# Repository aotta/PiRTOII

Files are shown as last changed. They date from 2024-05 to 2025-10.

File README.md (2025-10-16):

# PiRTO II
Intellivision flash multicart based on Pico clone

PiRTO II  is the new version of my PiRTO multicart DIY yourself based on cheap "purple" Raspberry Pi Pico clone.

(use "alternate_boot" version if your PiRTO doesn't start without resetting it and/or the console).

added v. 1.01: bug fixed (added test if more than 64 files in a folder)

added v. 1.02: bug fixed (fix for Coleco Rom from previous version)

added v. 1.03: bug fixed (issue in Chess after move #21)

added v. 1.04: bug fixed Missile Domination (added support for both RAM8 and RAM16) and added initialization fix used by gtortone for his "Minty" for better compatibility

added v. 1.05beta Arduino IDE version, new environment left more ram space and let games until 180kb run. Fixed Time Pilot. WARNING!!! THIS NEW VERSION USE A NEW FILE SYSTEM AND YOU NEED TO FORMAT THE PICO FLASH AND RE-UPLOAD ALL BIN+CFG FILES!!!!!

**WARNING!** "purple" Pico has not the same pinout of original Raspberry "green" ones, you MUST use the clone or you may damage your hardware.

**NOTE** FAT FS used for flash file management is quite simple, you can't use FILENAME LONGER THAN 32 BYTES INCLUDED SUFFIX!!!!! 
PLEASE RENAME YOUR BIN FILES OR THE GAMES WON'T START AT ALL!!! 

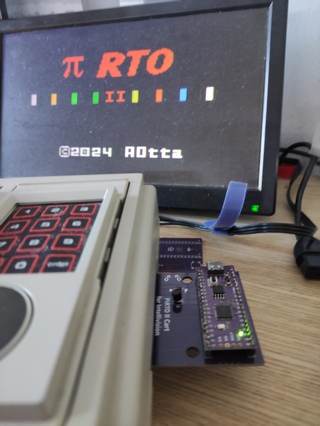
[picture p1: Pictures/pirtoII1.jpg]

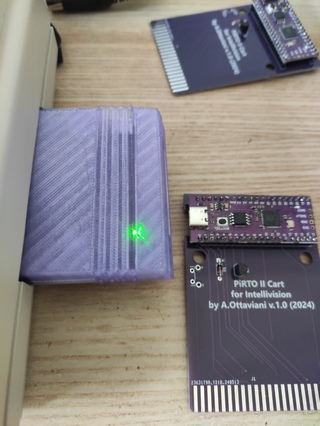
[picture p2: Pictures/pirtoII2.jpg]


Kicad project and gerbers files for the pcb are in the PCB folder, you need only a diode and a push buttons for resetting the cart if needed or want restart. 
Add you pico clone, and flash the firmware ".uf2" in the Pico by connecting it while pressing button on Pico and drop it in the opened windows on PC.
After flashed with firmware, and every time you have to change your ROMS repository, you can simply connect the Pico to PC and drag&drop "BIN" and "CFG“ files  into.

More info on AtariAge forum: https://forums.atariage.com/

Even if the diode should protect your console, **DO NOT CONNECT PICO WHILE INSERTED IN A POWERED ON CONSOLE!**
You can use any schottky diode, i usually put 1n4148

## Credits
Thank to Robin Robin Edwards and his A8PicoCart (https://github.com/robinhedwards/A8PicoCart), i found very smart his way to manage the Flash RAM and the USB updates, so i admit i took large parte of his code for it!.

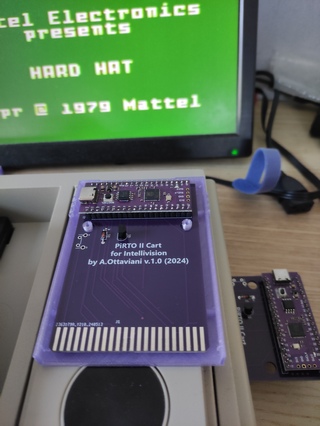
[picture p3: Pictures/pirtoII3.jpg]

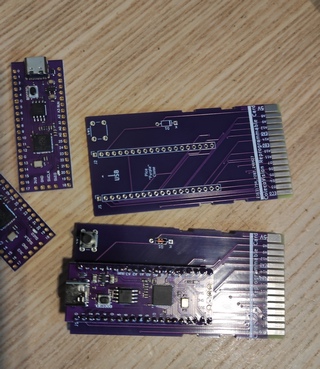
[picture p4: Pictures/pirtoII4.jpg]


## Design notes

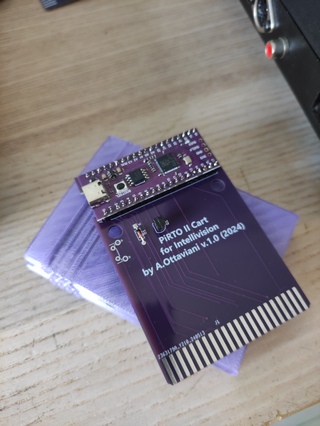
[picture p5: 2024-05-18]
Pictures/pirtoII6.jpg

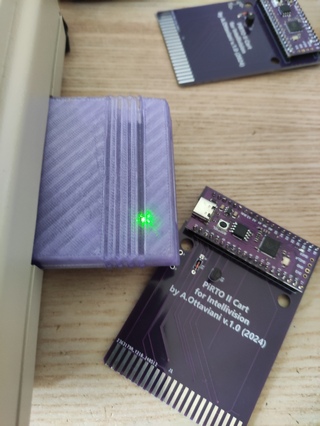
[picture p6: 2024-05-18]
Pictures/pirtoII7.jpg

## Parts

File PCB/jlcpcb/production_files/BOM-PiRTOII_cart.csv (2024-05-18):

Comment | Designator | Footprint | LCSC
Conn_01x20 | J2 | PinSocket_1x20_P2.54mm_Vertical
2x22 card edge connector | J1 | edge mounted 44 pin card edge connector (2x22 pin)
SW_Push | SW1 | SW_Tactile_SPST_Angled_PTS645Vx83-2LFS
Conn_01x20 | J3 | PinSocket_1x20_P2.54mm_Vertical
Diode | D1 | D_DO-35_SOD27_P7.62mm_Horizontal
BC547 | Q1 | TO-92_Inline

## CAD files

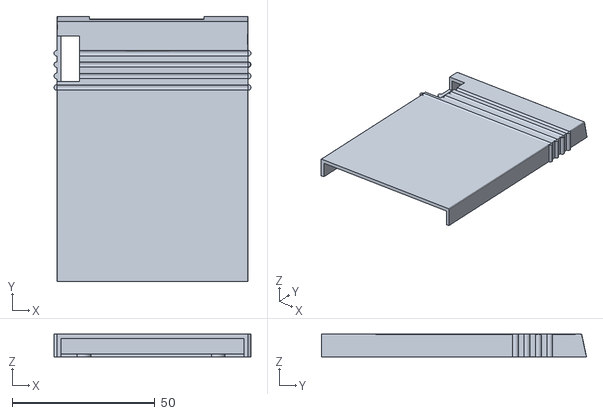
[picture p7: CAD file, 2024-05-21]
3DModel/PiRTOII/PiRTOII_Cart-Top (Meshed).stl
69.0 x 92.9 x 8.00

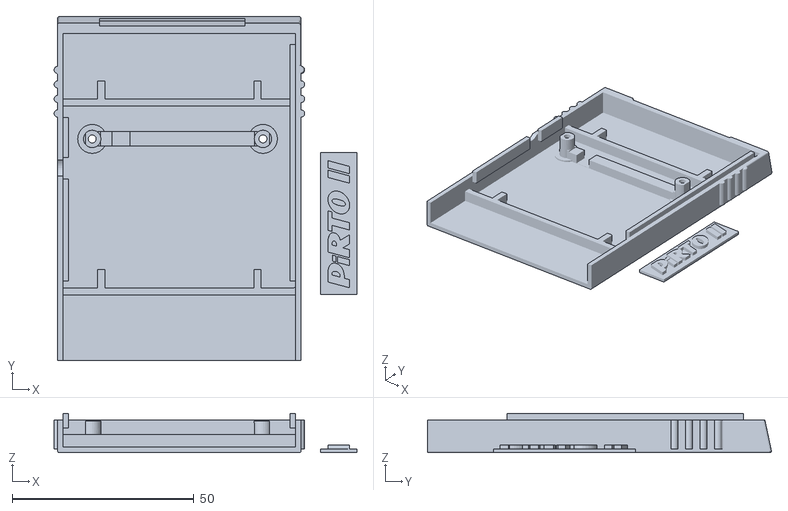
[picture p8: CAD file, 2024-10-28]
3DModel/Shell PirtoII Eskimo version/PiRTO_II-Cart-Bottom+Logo.stl
83.4 x 94.7 x 10.8

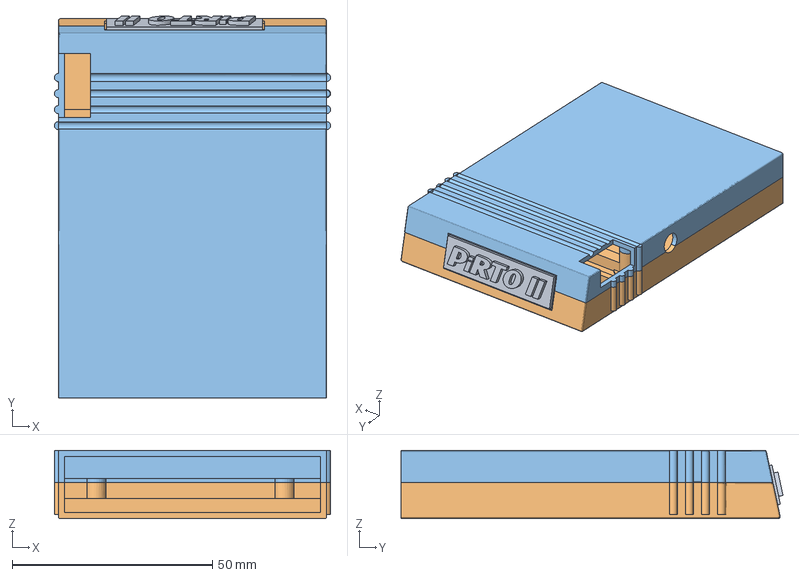
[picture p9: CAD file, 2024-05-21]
3DModel/PiRTOII/PiRTOII_Cart.FCStd
69.0 x 95.4 x 17.0 mm
Logo (Meshed)
Bot (Meshed)
Top (Meshed)

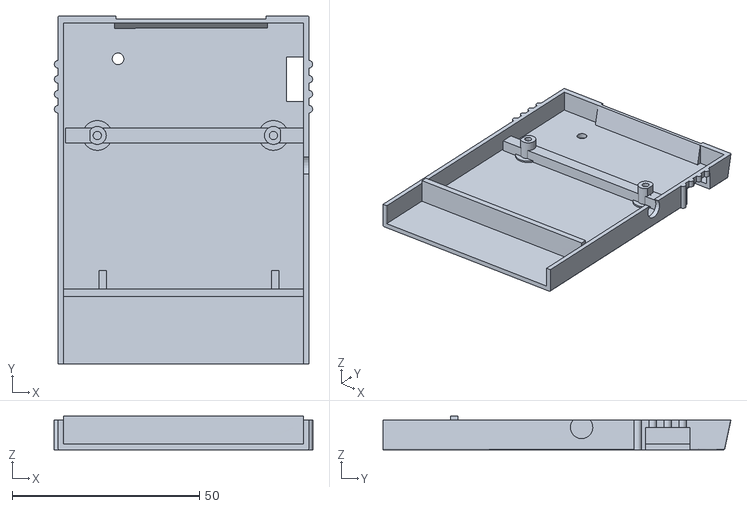
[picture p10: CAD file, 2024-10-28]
3DModel/Shell PirtoII Eskimo version/PiRTO_II-Cart-Top.stl
69.0 x 92.9 x 9.00

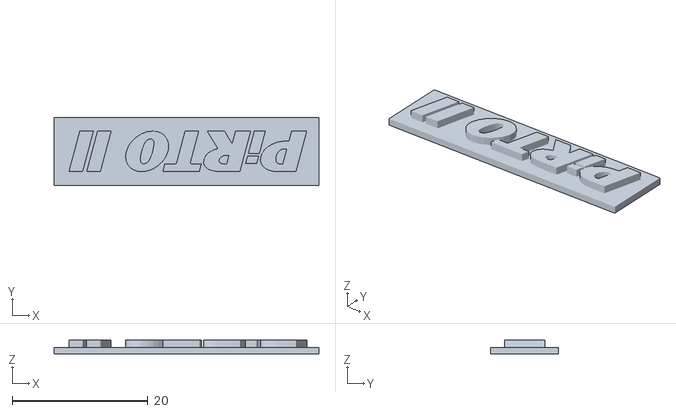
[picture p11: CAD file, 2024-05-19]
3DModel/PiRTOII/PiRTOII_Cart-Logo (Meshed).stl
39.0 x 10.0 x 2.10

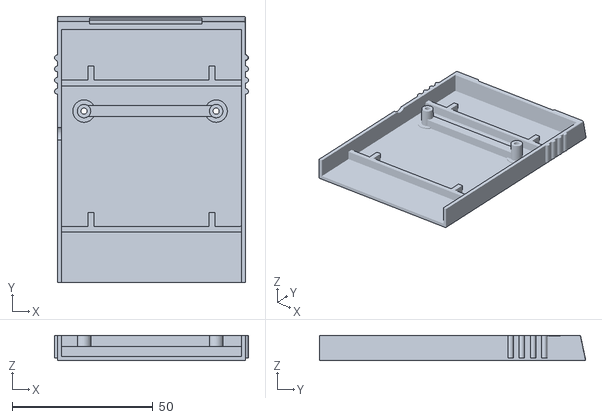
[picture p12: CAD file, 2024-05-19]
3DModel/PiRTOII/PiRTOII_Cart-Bot (Meshed).stl
69.0 x 94.7 x 9.00

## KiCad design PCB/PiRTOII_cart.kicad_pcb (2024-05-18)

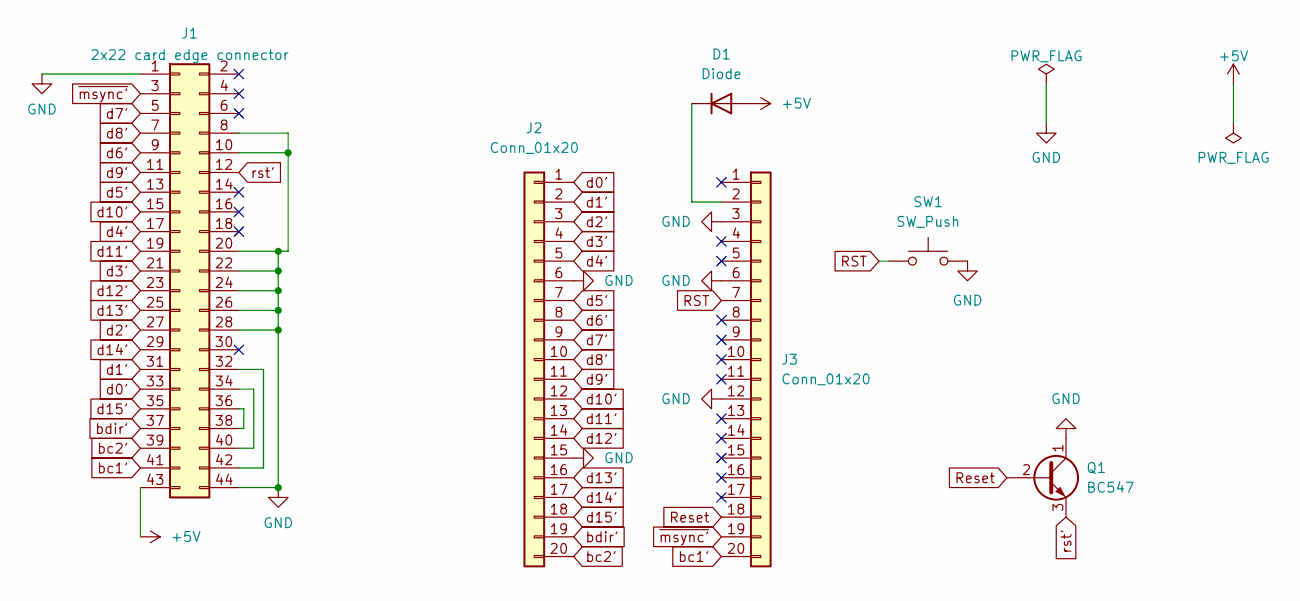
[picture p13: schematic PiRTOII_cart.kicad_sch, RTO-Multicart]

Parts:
D1: Diode; D_DO-35_SOD27_P7.62mm_Horizontal
J1: 2x22 card edge connector; edge mounted 44 pin card edge connector (2x22 pin)
J2, J3: Conn_01x20; PinSocket_1x20_P2.54mm_Vertical
Q1: BC547; TO-92_Inline
SW1: SW_Push; SW_Tactile_SPST_Angled_PTS645Vx83-2LFS

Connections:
+5V: D1.2 (A), J1.43
GND: J1.1, J1.8, J1.10, J1.20, J1.22, J1.24, J1.26, J1.28, J1.44, J2.6, J2.15, J3.3, J3.6, J3.12, Q1.1 (C), SW1.2
unnamed: D1.1 (K), J3.2
unnamed: J1.32, J1.42
unnamed: J1.34, J1.40
unnamed: J1.36, J1.38
RST: J3.7, SW1.1
Reset: J3.18, Q1.2 (B)
bc1': J1.41, J3.20
bc2': J1.39, J2.20
bdir': J1.37, J2.19
d0': J1.33, J2.1
d1': J1.31, J2.2
d2': J1.27, J2.3
d3': J1.21, J2.4
d4': J1.17, J2.5
d5': J1.13, J2.7
d6': J1.9, J2.8
d7': J1.5, J2.9
d8': J1.7, J2.10
d9': J1.11, J2.11
d10': J1.15, J2.12
d11': J1.19, J2.13
d12': J1.23, J2.14
d13': J1.25, J2.16
d14': J1.29, J2.17
d15': J1.35, J2.18
rst': J1.12, Q1.3 (E)
~msync': J1.3, J3.19

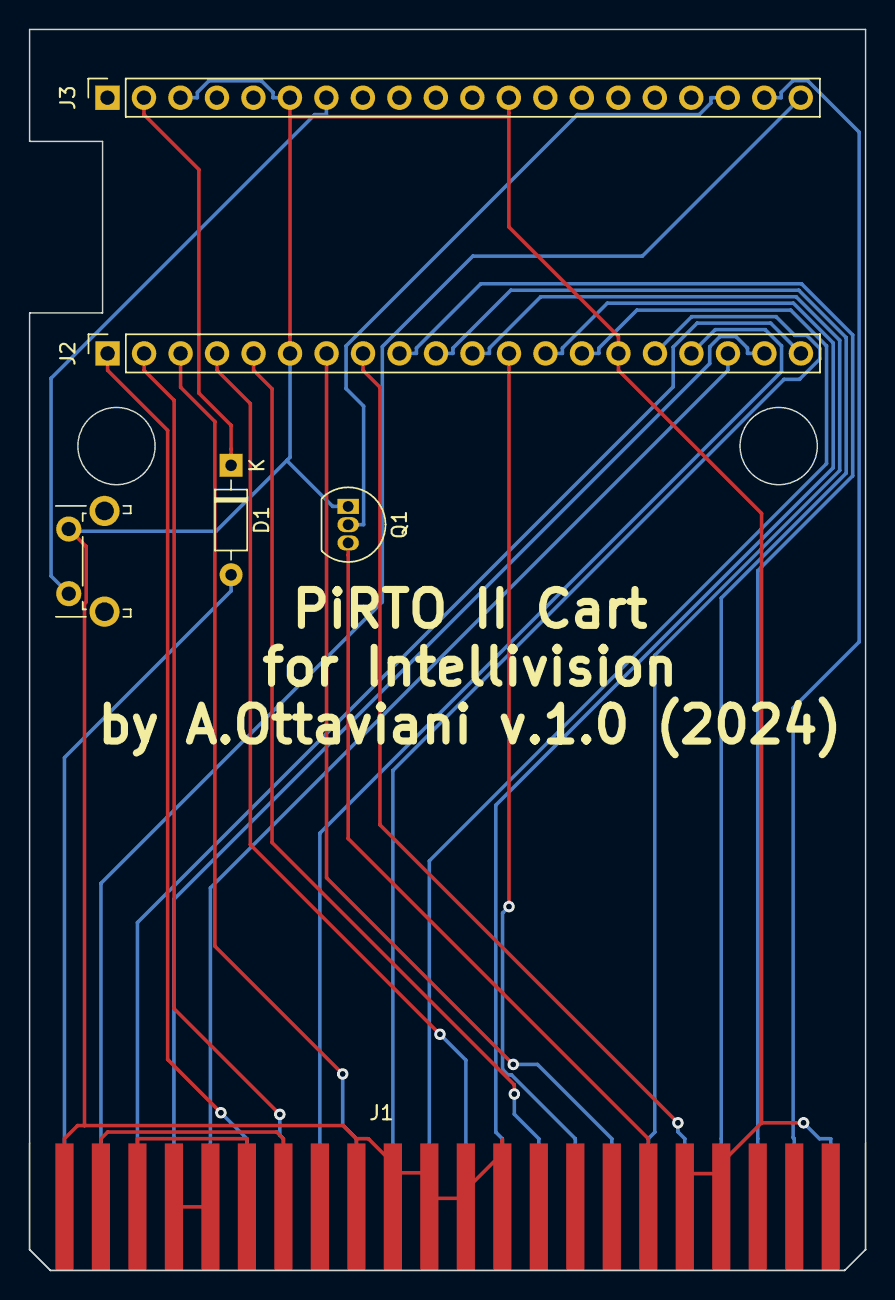
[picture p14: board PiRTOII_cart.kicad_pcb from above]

Board: 2 copper layers, 58.2 x 86.4 mm, 6 parts (0 on the bottom side), 29 nets.

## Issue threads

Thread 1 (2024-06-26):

Recommended edge connector option?

hadess, 2024-06-26:
I guess this question stands for most of your "flashcarts": which PCB thickness and edge connector finish do you recommend using? The defaults for my supplier are 1.6mm thick PCBs, and ENIG edge connector finish. Are those OK? What bevelling would you recommend?

aotta, 2024-06-26:
I used defaults also, in my case 1.6mm thick but Hasl with lead finish.
Enig should works fine too, but it's usually more expensive.
Gold fingers also may be a good options, but i wanted to keep all my
flashcart cheaper as possible.

Il giorno mer 26 giu 2024 alle ore 08:59 hadess ***@***.***>
ha scritto:

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

hadess, 2024-06-26:
The ENIG finish was relatively cheap (compared to shipping or VAT) and I went with 30 degrees bevelled edge as recommended here: https://www.retrorgb.com/determining-the-build-quality-of-a-game-cartridge.html

Thanks!

Closed 2025-03-10.

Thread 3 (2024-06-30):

A couple of design questions

SukkoPera, 2024-06-30:
I'm working on a modified version of this cart that used the original Pico board (just because I have plenty of those) and I have a few questions on the design. Please note that I don't know anything about the Intellivision. I have bought one some time ago but I have no carts, hence my interest in this project :). So please excuse me if my questions are naive, it's really the first time I look at this stuff:

* I see that pins 8 and 10 are permanently grounded. I can understand it for pin 8, which, according to [the pinout](https://wiki.intellivision.us/index.php/Cartridge_Port) is the EXT_VIDEO input (I guess it's for reducing noise), but not for pin 10: it looks like it is the MCLK _output_, and forcing it to ground doesn't sound good to me. I think it should just be left unconnected. Maybe you wanted to ground pins 6 (EXT_AUDIO) and 8 but you miscounted? Just a thought :).
* Same for pin 20, ROM_DISABLE: why is it grounded?
* The reset circuit does not look correct to me. The BC547 is an NPN transistor and seeing its collector connected to GND is very odd. Besides, I think some resistors should be added in series with the base and collector. Can you please explain the rationale behind it?

Thanks a lot! :)

SukkoPera, 2024-06-30:
This would be my proposal for the reset circuit:
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

(_reset_inty_out_ is the signal coming from the Pico, I've just renamed it)

SukkoPera, 2024-12-22:
I have finally tested my above proposal for the reset circuit and I can now say that it works perfectly! ;)

aotta, 2024-12-22:
Thank @SukkoPera for the alternative design, so close the issue

Closed 2024-12-22.

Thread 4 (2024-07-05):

Black screen on power up

repetto74, 2024-07-05:
Hi,

I have built this project. All soldering is good and checked. I used a diode 1N4148 and a BC547 transistor. No pushbutton installed for the reset.
Pico programmed from USB and bin files copied in the "PICOII" drive showing up on the desktop after firmware programming.

I get a black screen with a background video noise when I power up the Intellivision. This is the normal behaviour when no cart is inserted in the console.
Pico led is not lighting up. Looks like the Pico does not get power. Any idea what this could be?

aotta, 2024-07-05:
one user experimented similar issue due to not recognizing MSYNC signal at
boot, you could try the alternate firmware i just uploaded if it help

Il giorno ven 5 lug 2024 alle ore 19:27 repetto74 ***@***.***>
ha scritto:

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

repetto74, 2024-07-05:
Ok thanks I will give a try with the alternate firmware thanks :-)

repetto74, 2024-07-05:
I reprogrammed the pico with the alternate firmware (noticed that games binaries copied in the Pico are not cancelled but I assume this is normal).
Unfortunately same behaviour. Black screen with video noise in the background.

repetto74, 2024-07-05:
The pico is the purple clone as stated by the Ali merchant. Still a doubt maybe on the pinout of this one but I think it is the good one.
This is the one I picked for this project: https://www.aliexpress.com/item/1005007052696317.html?spm=a2g0o.order_list.order_list_main.5.3cc318022FPEpg

aotta, 2024-07-05:
So, sorry but that Pico clone has a different pinout than the usual
"purple" clone and it doesn't work with PiRTO.
As you could see, for example it has GND at pin no. 3 while the right one
has GND at pin no. 6, as better showed in the repository from which i was
inspired: https://github.com/robinhedwards/A8PicoCart

Il giorno ven 5 lug 2024 alle ore 20:13 repetto74 ***@***.***>
ha scritto:

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

repetto74, 2024-07-05:
Ok thanks now it is clear :-) ! I need to source the good Pico clone.

repetto74, 2024-07-05:
I finally found the good purple pico and ordered. This should fix the issue :-).

https://www.aliexpress.com/item/1005004277013272.html?spm=a2g0o.order_list.order_list_main.5.73e41802q3bytF

emilen72, 2024-07-06:
Hi, I have the same behavior and I built the cart with the same latest purple clone you ordered. The cart works but I need every time:
1) insert the cart
2) turn on the console
3) reset the console
4) reset the cart (install button or short with tweezers)

then the start menu and game are listed.
Remember to add the 0.cfg file in the root otherwise the games won’t start.

hope this help

aotta, 2024-07-06:
The user at atariage solved with the alternative FW in published yesterday, please @emilen72 check it you too

aotta, 2024-07-06:
A Pico clone with different pinout will never work without changes in PCB, and also trying it could damage your Pico and/or the console!

mamejay, 2024-07-07:
> The user at atariage solved with the alternative FW in published yesterday, please @emilen72 check it you too

PERFECT!! This works well.

emilen72, 2024-07-08:
> The user at atariage solved with the alternative FW in published yesterday, please @emilen72 check it you too

Ok, it work… only noted that on every game, after that the game start well, the led blink 1 time endless… its ok too?

bataais, 2025-01-31:
Unfortunately USCF Chess 'hangs' at white move 21 on the PiRTOii. Clocks are counting, but no move is made.
I have the right .bin and .cfg files.

Try it with C vs C, Color (Left Controller ENT, ENT, 8).

Seems a RAM problem..

Closed 2025-03-10.

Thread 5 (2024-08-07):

Incoherent code in "void __not_in_flash_func(core1_main())", in "inty_cart.c" module.

dombru54, 2024-08-07:
Hello,
There is an unconditional "break" in this "for", "break" should be in "if".
if (hacks>0) {
          for (int i=0; i<maxHacks;i++) {
            if (parallelBus==HACK[i]) {
              dataOut=HACK_CODE[i];
              deviceAddress = true;
            }
            break;
          }
        }

aotta, 2024-08-07:
Hi, you're right, break position fixed in source

dombru54, 2024-08-07:
Your welcome !
Congratulations, aotta, for your shared project.
I am putting it into service

Closed 2024-08-07.

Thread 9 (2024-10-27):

Question about rPico pinouts

8lall0, 2024-10-27:
I would like to ask what are the differences between the original rPico and the purple clone :)

Thanks!

crystalct, 2024-11-06:
Could you tell us where to read the characteristics of this clone which make it safe for the use of 5V in the GPIOs.....

SukkoPera, 2024-12-22:
It is never clearly stated, but I think that the board was designed for the purple clone because it can be bought with much larger flash size than the official board (16 MB vs 2 MB), thus more ROMs can be put on it.

The clone has no special characteristics that make it 5V-tolerant, it's just the RP2040 that [is *unofficially* 5V-tolerant](https://hackaday.com/2022/09/25/pi-pico-w-does-pcmcia-gets-this-ibm-pc110-online/#comment-6516402).

Anyway, you might be happy to know that I have designed [a variant of this board](https://github.com/SukkoPera/PiRTOII) that uses the official Pico and (re)introduces proper level shifting. Feel free to check it out! ;)

aotta, 2024-12-22:
I confirm the only real reasons why i used the purple clone is the 15mb flash free instead of the 780~kb of the green one.
Thank to @SukkoPera for his variant, now anyone could choose his favourite flavours.

Closed 2024-12-22.

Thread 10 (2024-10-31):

Games not loading, but Booting OK to the menu screen.

roninfourseven, 2024-10-31:
I have built a PiRTOII using PCBWay to manufacture the PCBs from the gerbers on here.

The Pi is a purple Pi from Ali Express and I bought two, one is installed in one of your PiColecos and works fine BTW.

The PiRTOII boots fine to the menu screen and I can navigate to ROMs (These have a BIN extension and the filenames are less than 32 characters), however whin I select a file it sits with the green light pulsing and the Intellivision is frozen.

The Intellivision works fine with normal carts.

I have tried both firmware versions but get the same and I have reflowed all the soldering.

One thing, my Intellivision is a UK model and I don't know if the ROMs are region sensitive.

Any help would be useful, thanks

Jon

roninfourseven, 2024-10-31:
I didn't, can you elaborate a little more please

MMarcoux66, 2024-10-31:
Look at this thread...  https://forums.atariage.com/topic/366700-pirto-ii-multicart-just-published/page/2/

roninfourseven, 2024-10-31:
Thank you

roninfourseven, 2024-10-31:
OK so 0.cfg has been added and it boots, but ends up at a black screen with the Purple Pi flashing it's light every other second.

roninfourseven, 2024-10-31:
Good news, I downloaded the cfg files from atariage and it seems to be working :)

aotta, 2024-10-31:
Happy you solved, closing.

Closed 2024-10-31.

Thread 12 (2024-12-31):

Diode value?

deelowe, 2024-12-31:
Perhaps I missing it, but I can't seem to find specifications for the diode used in the design. Can the part details be provided?

aotta, 2024-12-31:
Any diode should works, i usually use 1n4148

Closed 2024-12-31.

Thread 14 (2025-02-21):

Richiesta informazioni su progetto PIRTOII

Fing972, 2025-02-21:
Salve,
innanzi tutto complimenti per il progetto, avevo già iniziato a seguire la versione 1 ma, ora che mi sono deciso a volerla realizzare, vorrei direttamente  puntare alla versione 2 ma avrei necessità di alcuni chiarimenti, se possibile, dato che non sono particolarmente esperto.
Per prima cosa ho studiato il PCB e ho visto che è realizzato con un pico purple che dovrebbe supportare i 5v.
Ho letto che ufficialmente il pico lavora a 3.3v, io ho acquistato in passato dei pico e sono la versione yd-rp2040 a 16mb che probabilmente hanno un pinout da confrontare bene con il purple e forse dovrei inserire dei level shifter 3.3-5v per essere sicuro.
Il sorgente della prima versione del PIRTO era basato sull'arduino IDE (.ino) mentre la seconda versione ho dovuto capire come funziona l'SDK per raspberry, poco male, un po di esperienza in più e dopo un po sono riuscito a compilare il tutto.
Qui arrivano i dubbi.
Le rom nella prima versione venivano messe nella sdcard mentre non ho capito bene nella seconda come vengono gestite e come viene utilizzato il pacchetto intybasic con dentro i sorgenti basic per i title.
Grazie in anticipo per i chiarimenti.
Saluti.
Alessandro

aotta, 2025-02-22:
Una volta caricato il firmware, se connetti la pirto al pc via usb (non inserita nella console) si apre una finestra con la cartella flash e puoi copiare i file bin+cfg con un semplice drag & drop.
Il codice intybasic è per il menu ma non ti serve modificarlo

Fing972, 2025-03-05:
Salve,
ho realizzato un prototipo utilizzando però un pico yd-rp2040 con 16mb.
ho adattato la piedinatura e modificate le impostazioni per il tipo di memoria.
La compilazione è andata a buon fine, ho scritto il firmware e sull'intellivision appare la schermata principale.
Il problema che ho è che una volta effettuato il flash del firmware il pico non mi viene visto, una volta collegato al PC, come memoria di massa e quindi non riesco a copiare le rom. Se vado in bootsel e copio qualcosa, naturalmente poi i dati vengono persi.
Il pc ad un certo punto mi da un errore tipo usb non riconosciuto.
Se invece metto il firmware del micropyton, dopo il flash me lo riconosce come memoria di massa di circa 15mb.
Cosa potrebbe essere andato storto, ho provato tutte le versioni di firmware.
Forse qualche impostazione del flash_fs ?
Grazie.

aotta, 2025-03-05:
Il sistema "doppio" è gestito con le librerie TinyUSB, devi installarle e selezionarla come USBStrack nel compilatore Arduino IDE

Closed 2025-02-22.

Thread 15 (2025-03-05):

Problemi con il pico dopo il flash del firmware

Fing972, 2025-03-05:
Salve,
ho realizzato un prototipo utilizzando però un pico yd-rp2040 con 16mb.
Ho adattato la piedinatura e modificate le impostazioni per il tipo di memoria.
La compilazione è andata a buon fine, ho scritto il firmware e sull'intellivision appare la schermata principale.
Il problema che ho è che una volta effettuato il flash del firmware il pico non mi viene visto, una volta collegato al PC, come memoria di massa e quindi non riesco a copiare le rom.
Se vado in bootsel e copio qualcosa, naturalmente poi i dati vengono persi.
Il PC ad un certo punto mi da un errore tipo usb non riconosciuto.
Se invece metto il firmware del CircuitPython, dopo il flash me lo riconosce come memoria di massa di circa 15mb (è solo un esempio, cosi ho capito che in qualche modo il mio pico funziona come memoria di massa).
Cosa potrebbe essere andato storto, ho provato tutte le versioni di firmware.
Forse qualche impostazione del flash_fs che varie in base al tipo di flash memory ?
Grazie.

Closed 2025-03-10.

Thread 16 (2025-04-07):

What kind of diode ? (not an issue)

Giandj, 2025-04-07:
Hi Andrea,
what kind of diode do you use in your PIRTO II ?

I see the bom files, and readme.md, but no information about diode...

Instead Transistor is a  "BC547A NPN 45V 0.1A TO-92" ? (schematics is not so clear/absent ?)

Can you help me ?
Thank you

aotta, 2025-04-08:
already answered in a closed issue, and updated the readme for any convenience.
Anyway, any schottky diode should works, i usually put 1n4148 since i've tons

Closed 2025-04-08.

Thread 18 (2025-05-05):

error in latest firmware PIRTOII_cart_1.03.uf2

Giandj, 2025-05-05:
Hi,
After installing new firmware **PIRTOII_cart_1.03.uf2**, KChess game loads, but
after pressing joypad-wheel to enter in game it exit immediatly (due to an error, I Think)
whit a black screen on TV from game, hanging Pirto II... Until Reset Button wil be pressed...to reboot PiRTO II

So I think this new firmware has an issue with KChess game, other games works perfectly like in previously version  **PIRTOII_cart_1.01.uf2**

If I try to reflash old firmware PIRTOII_cart_1.01.uf2, the KChess game works very well (instead).

**I prefer to remain on PIRTOII_cart_1.01.uf2, most stable...**

Thank you

aotta, 2025-05-05:
With v.1.01, Chess hangs after 21 moves. V.1.03 fixed it. Did you try the ” alternate_boot” version?

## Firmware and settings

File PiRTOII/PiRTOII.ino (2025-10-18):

/*
//                       PiRTO II Flash MultiCART by Andrea Ottaviani 2024
//
//  Intellivision flash multicart based on Raspberry Pico board -
//
//  More info on https://github.com/aotta/ 
//
//   parts of code are directly from the A8PicoCart project by Robin Edwards 2023
//  
//   Needs to be a release NOT debug build for the cartridge emulation to work
// 
//   Edit myboard.h depending on the type of flash memory on the pico clone//
//
//   v. 1.03 2025-09-04 : Added check maxfile 
//   v. 1.05 porting to Arduino IDE - support rom until 180kb (Time Pilot)
//
*/

//#define intydebug // for debug print on intyscreen

/*
#include <stdio.h>
#include <stdlib.h>

#include "tusb.h"
*/
//#include "ff.h"

#include "hardware/gpio.h"
#include "pico/platform.h"
#include "pico/stdlib.h"
#include "hardware/vreg.h"
#include "pico/multicore.h"
#include "hardware/flash.h"
#include "hardware/sync.h"
#include "string.h"
#include "rom.h"
#include "dir_entry.hpp"
// include for Flash files
#include "SPI.h"
#include "SdFat_Adafruit_Fork.h"
#include "Adafruit_SPIFlash.h"
#include "Adafruit_TinyUSB.h"
Adafruit_FlashTransport_RP2040 flashTransport;
Adafruit_SPIFlash flash(&flashTransport);

// file system object from SdFat
FatVolume fatfs;
FatFile root;
FatFile file;

// USB Mass Storage object
Adafruit_USBD_MSC usb_msc;
// Check if flash is formatted
bool fs_formatted;
// Set to true when PC write to flash
bool fs_changed=false;


// Pico pin usage definitions

#define B0_PIN    0
#define B1_PIN    1
#define B2_PIN    2
#define B3_PIN    3
#define B4_PIN    4
#define B5_PIN    5
#define B6_PIN    6
#define B7_PIN    7
#define F0_PIN    8
#define F1_PIN    9
#define F2_PIN    10
#define F3_PIN    11
#define F4_PIN    12
#define F5_PIN    13
#define F6_PIN    14
#define F7_PIN    15
#define BDIR_PIN  16
#define BC2_PIN   17
#define BC1_PIN   18
#define MSYNC_PIN 19
#define RST_PIN   20
#define LED_PIN   25

// Pico pin usage masks

#define B0_PIN_MASK     0x00000001L // gpio 0
#define B1_PIN_MASK     0x00000002L
#define B2_PIN_MASK     0x00000004L
#define B3_PIN_MASK     0x00000008L
#define B4_PIN_MASK     0x00000010L
#define B5_PIN_MASK     0x00000020L
#define B6_PIN_MASK     0x00000040L
#define B7_PIN_MASK     0x00000080L

#define F0_PIN_MASK     0x00000100L
#define F1_PIN_MASK     0x00000200L
#define F2_PIN_MASK     0x00000400L
#define F3_PIN_MASK     0x00000800L
#define F4_PIN_MASK     0x00001000L
#define F5_PIN_MASK     0x00002000L
#define F6_PIN_MASK     0x00004000L
#define F7_PIN_MASK     0x00008000L  // gpio 15

#define BDIR_PIN_MASK   0x00010000L // gpio 16
#define BC2_PIN_MASK    0x00020000L // gpio 17
#define BC1_PIN_MASK    0x00040000L // gpio 18
#define MSYNC_PIN_MASK  0x00080000L // gpio 19
#define RST_PIN_MASK    0x00100000L // gpio 20
#define LED_PIN_MASK    0x02000000L // gpio 25

// Aggregate Pico pin usage masks
#define BC1e2_PIN_MASK  0x00060000L
#define BX_PIN_MASK     0x000000FFL
#define FX_PIN_MASK     0x0000FF00L
#define DATA_PIN_MASK   0x0000FFFFL
#define BUS_STATE_MASK  0x00070000L
#define ALL_GPIO_MASK  	0x021FFFFFL
#define ALWAYS_IN_MASK  (BUS_STATE_MASK)
#define ALWAYS_OUT_MASK (LED_PIN_MASK)


#define SET_DATA_MODE_OUT   gpio_set_dir_out_masked(DATA_PIN_MASK)
#define SET_DATA_MODE_IN    gpio_set_dir_in_masked(DATA_PIN_MASK)

#define resetLow()  gpio_set_dir(RST_PIN,true); gpio_put(RST_PIN,true); //  Pirto to INTV BUS ; RST Output set to 0
#define resetHigh() gpio_set_dir(RST_PIN,true); gpio_put(RST_PIN,false); // RST is INPUT; B->A, INTV BUS to TEENSY

// Inty bus values (BC1+BC2+BDIR) GPIO 18-17-16

#define BUS_NACT  0b000  //0
#define BUS_BAR   0b001  //1
#define BUS_IAB   0b010  //2
#define BUS_DWS   0b011  //3
#define BUS_ADAR  0b100  //4
#define BUS_DW    0b101  //5
#define BUS_DTB   0b110  //6
#define BUS_INTAK 0b111  //7


unsigned char busLookup[8];

char RBLo,RBHi;
#define BINLENGTH  1024*96//65536L
#define RAMSIZE  0x2100
uint16_t ROM[BINLENGTH];

uint16_t RAM[RAMSIZE];
#define maxHacks 32
uint16_t HACK[maxHacks];
uint16_t HACK_CODE[maxHacks];

char curPath[256];
char path[256];
unsigned char files[256*64] = {0};
unsigned char nomefiles[32*25] = {0};
int fileda=0,filea=0;
volatile char cmd=0;
char errorBuf[40];
bool cmd_executing=false;

unsigned int parallelBus2;
  
unsigned int romLen;
unsigned int ramfrom = 0;
unsigned int ramto =   0;
unsigned int mapfrom[80];
unsigned int mapto[80];
unsigned int maprom[80];
int mapdelta[80];
unsigned int mapsize[80];
unsigned int addrto[80];
unsigned int RAMused = 0;
volatile bool RAM8 = false;
unsigned int tipo[80];  // 0-rom / 1-page / 2-ram
unsigned int page[80];  // page number

char substr[100];

int slot;
int hacks;

int base=0x17f;

uint32_t selectedfile_size;    // BIN file size
char longfilename[60];         // long file name (trunked) 
char mapfilename[60];          // map cfg file name
char testfilename[60];         // for check if directory
char rewindfilename[60];       // for rewind browsing
char rewindprev[60];       // for rewind browsing
int lenfilename; 
char tiposcelta[9];
bool pressed=false;



// Callback invoked when received READ10 command.
// Copy disk's data to buffer (up to bufsize) and
// return number of copied bytes (must be multiple of block size)
int32_t msc_read_cb (uint32_t lba, void* buffer, uint32_t bufsize)
{
  // Note: SPIFLash Block API: readBlocks/writeBlocks/syncBlocks
  // already include 4K sector caching internally. We don't need to cache it, yahhhh!!
  return flash.readBlocks(lba, (uint8_t*) buffer, bufsize / 512) ? bufsize : -1;
}

// Callback invoked when received WRITE10 command.
// Process data in rom_table to disk's storage and
// return number of written bytes (must be multiple of block size)
int32_t msc_write_cb (uint32_t lba, uint8_t* buffer, uint32_t bufsize)
{
 
  // Note: SPIFLash Block API: readBlocks/writeBlocks/syncBlocks
  // already include 4K sector caching internally. We don't need to cache it, yahhhh!!
  return flash.writeBlocks(lba, buffer, bufsize / 512) ? bufsize : -1;
}

// Callback invoked when WRITE10 command is completed (status received and accepted by host).
// used to flush any pending cache.
void msc_flush_cb (void)
{
  // sync with flash
  flash.syncBlocks();

  // clear file system's cache to force refresh
  fatfs.cacheClear();

  fs_changed = true;

}


////////////////////////////////////////////////////////////////////////////////////
//                     RESET
////////////////////////////////////////////////////////////////////////////////////
void resetCart() {
  gpio_init(MSYNC_PIN);
  gpio_set_dir(MSYNC_PIN,false);
  gpio_set_pulls(MSYNC_PIN,false,true);
  gpio_put(LED_PIN,false);
  resetHigh();
   sleep_ms(30);  // was 20 for Model II; 30 works for both
   resetLow();
  //sleep_ms(3);  // was 2 for Model II; 3 works for both
 
  //while ((gpio_get(MSYNC_PIN)==1)) ;
    
  sleep_ms(1);  // was 1 for Model II; 
 resetHigh();
 gpio_put(LED_PIN,true);
   
}


/*
 Theory of Operation
 -------------------
 Inty sends command to mcu on cart by writing to 50000 (CMD), 50001 (parameter) and menu (50002-50641) 
 Inty must be running from RAM when it sends a command, since the mcu on the cart will
 go away at that point. Inty polls 50001 until it reads $1.
*/
#pragma GCC push_options
#pragma GCC optimize ("O3")

void __time_critical_func(setup1()) {   //HandleBUS()

  unsigned int lastBusState, busState1;
  unsigned int busSt1, busSt2;
  unsigned int parallelBus;
  unsigned int dataOut, dataInd;
  unsigned int dataWrite=0;
  unsigned char busBit;
  bool deviceAddress = false; 
  unsigned int curPage=0;
  unsigned int checpage=0;
  int exitBUS;

  //multicore_lockout_victim_init();	

  sleep_ms(480);

  busState1 = BUS_NACT;
  lastBusState = BUS_NACT;
  
  dataOut=0;

    gpio_set_dir_in_masked(ALWAYS_IN_MASK);
    gpio_set_dir_out_masked(ALWAYS_OUT_MASK);
 
    // Initial conditions
    SET_DATA_MODE_IN;
   
while(1) {
    // Wait for the bus state to change
  
    do {
    } while (!((gpio_get_all() ^ lastBusState) & BUS_STATE_MASK));
    // We detected a change, but reread the bus state to make sure that all three pins have settled
     lastBusState = gpio_get_all();

    busState1 = ((lastBusState & BUS_STATE_MASK)>> BDIR_PIN); //if gpio9    
   
    busBit = busLookup[busState1];
    // Avoiding switch statements here because timing is critical and needs to be deterministic
    if (!busBit)
    {
      // -----------------------
      // DTB
      // -----------------------
      // DTB needs to come first since its timing is critical.  The CP-1600 expects data to be
      // placed on the bus early in the bus cycle (i.e. we need to get data on the bus quickly!)
	    if (deviceAddress)
      {
        // The data was prefetched during BAR/ADAR.  There isn't nearly enough time to fetch it here.
        // We can just output it.
        SET_DATA_MODE_OUT;
        gpio_put_masked(DATA_PIN_MASK,dataOut);
        asm inline ("nop;nop;nop;nop;");

       /// while ((gpio_get_all() & BC1_PIN_MASK)); // wait while bc1 & bc2 are high... it's enough test BC1
        while(((gpio_get_all() & BC1e2_PIN_MASK)>>BC2_PIN)==3);
        //asm inline (delWR); //150ns
        
              
       SET_DATA_MODE_IN;
      }
     }
    else
    {
      busBit >>= 1;
      if (!busBit)
      {
        // -----------------------
        // BAR, ADAR
        // -----------------------
	   if (busState1==BUS_ADAR) {
	     if (deviceAddress)  
      		{
        // The data was prefetched during BAR/ADAR.  There isn't nearly enough time to fetch it here.
        // We can just output it.
       	SET_DATA_MODE_OUT;
        gpio_put_masked(DATA_PIN_MASK,dataOut);
        
        while((gpio_get_all() & BC1_PIN_MASK)>>BC1_PIN); //wait BC1 go down 
        //asm inline (delWR); //150ns

         SET_DATA_MODE_IN;
        
      		}
	   }
      /// ELSE is BAR   
        // Prefetch data here because there won't be enough time to get it during DTB.
        // However, we can't take forever because of all the time we had to wait for
        // the address to appear on the bus.
        SET_DATA_MODE_IN;
       // We have to wait until the address is stable on the bus
        // waiting bus is stable 66 nop at 200mhz is ok/85 at 240
    
       while(((parallelBus=gpio_get_all()) & BDIR_PIN_MASK));  // wait DIR go low for finish BAR cycle 
       //asm inline (delRD); //150ns
    
       parallelBus = gpio_get_all()& 0xFFFF; 

       deviceAddress = false;
         
       // Load data for DTB here to save time
           for (int8_t i=0; i <= slot; i++) {
            if ((parallelBus - maprom[i]) <= mapsize[i]) {
              if (tipo[i]==0) {
                dataOut=ROM[(parallelBus - mapdelta[i])];
                deviceAddress = true;
                break;
              }
              if (tipo[i]==1) {
                if (page[i]==curPage) {
                  dataOut=ROM[(parallelBus - mapdelta[i])];
                  deviceAddress = true;
                  break;
                }
                if ((parallelBus & 0xfff)==0xfff) {
                  checpage=1;
                   deviceAddress = true;
                  break;
                }
              }
              if (tipo[i]==2) {
                dataOut=RAM[parallelBus - ramfrom];
                deviceAddress = true;
                break;
              } 
            }    
          }
  
        if (hacks>0) {
          for (int i=0; i<maxHacks;i++) {
            if (parallelBus==HACK[i]) {
              dataOut=HACK_CODE[i];
              deviceAddress = true;
	          }
            break;
          }
        } 
      }
      else
      {
         busBit >>= 1;
        if (!busBit)
        {
          // -----------------------
          // DWS
          // -----------------------
       
          if (deviceAddress) {

            SET_DATA_MODE_IN;
           
            dataWrite = gpio_get_all() & 0xFFFF; 
        
          if (RAMused == 1) {
              if (RAM8) 
                RAM[parallelBus-ramfrom]=dataWrite & 0xFF;
              else 
                RAM[parallelBus-ramfrom]=dataWrite;
            } 
           if ((checpage == 1) && (((dataWrite >> 4) & 0xff) == 0xA5)) {
              curPage=dataWrite & 0xf;
              checpage=0;
           }
           
        }
        else
        {
         // -----------------------
         // NACT, IAB, DW, INTAK
         // -----------------------
         // reconnect to bus
           parallelBus2=parallelBus;
           SET_DATA_MODE_IN;
        }
        
        }
      } 
    }    
  }
} 

#pragma GCC pop_options


////////////////////////////////////////////////////////////////////////////////////
//                     Error(N)
////////////////////////////////////////////////////////////////////////////////////
void error(int numblink){
  Serial.print("Error ");
  Serial.println(numblink);
  while(1){
    gpio_set_dir(25,GPIO_OUT);
    
    for(int i=0;i<numblink;i++) {
      gpio_put(25,true);
      sleep_ms(600);
      gpio_put(25,false);
      sleep_ms(500);
      Serial.print("Error ");
      Serial.println(numblink);
    }
  sleep_ms(2000);
  }
}

/////////////////////////////////
// print on mfile on inty
////////////////////////////////
void printInty(char *temp) {
  for (int i=0;i<120;i++) RAM[0x17f+i]=0;
  for (int i=0;i<60;i++) {
    RAM[0x17f+i*2]=temp[i];
    if (temp[i]==0) {
      RAM[0x17f+i*2]='*';
      break;
    }
  }
  sleep_ms(1000);
} 
int read_directory(char *path) {
  //  if (path[0]==0) strcpy(path,'/');
    Serial.print("Read_directory: ");
    Serial.println(path);
    int ret = 0;
    num_dir_entries = 0;
    DIR_ENTRY *dst = (DIR_ENTRY *)&files[0];

    FatFile dir;
    if (dir.open(path, O_RDONLY)) {
    //if (dir.open("/", O_RDONLY)) {
        FatFile file;
        while (num_dir_entries < 64 && file.openNext(&dir, O_RDONLY)) {
            char filename[256];
            file.getName(filename, sizeof(filename));
            
            if (strcmp(filename, ".") == 0 || strcmp(filename, "..") == 0) {
                file.close();
                continue;
            }
            
            if (file.isHidden() || file.isSystem()) {
                file.close();
                continue;
            }
            
            dst->isDir = file.isDir();
            if (!dst->isDir && !is_valid_file(filename)) {
                file.close();
                continue;
            }
            
            // Usa lo stesso nome per entrambi i campi
            strncpy(dst->long_filename, filename, 31);
            dst->long_filename[31] = 0;
            strncpy(dst->filename, filename, 12);
            dst->filename[12] = 0;
            
            dst->full_path[0] = 0;
            dst++;
            num_dir_entries++;
            
            file.close();
        }
        dir.close();
        
        qsort((DIR_ENTRY *)&files[0], num_dir_entries, sizeof(DIR_ENTRY), entry_compare);
        ret = 1;
    }
    else {
        Serial.println("Can't read directory");
    }
    
    return ret;
}
/////////////////////////////////////////////////////////////////////////////////////////
///////////////////////////////* load file in  ROM */////////////////////////////////////
/////////////////////////////////////////////////////////////////////////////////////////

void load_file(char *filename) {
	
  int car_file = 0;
  int  size = 0;
	Serial.print("load file: ");
  Serial.println(filename);
  //printInty("loadfile");
  //printInty(filename);

 
	if (!(file.open(filename))) {
		Serial.print("Can't open file ");
    Serial.println(filename);
    error(2);
	}

 Serial.println("Start load");
 size=0;
 while ((file.available()) && (size<(BINLENGTH-1))) {
  
    RBHi = file.read();
    RBLo = file.read();
   
    ROM[size]= RBLo | (RBHi << 8);
	  size++;
   
  }
  if (size==(BINLENGTH-1)) Serial.println("Max size exceeded");
closefile:
  romLen=size;
  RAM[base+202]=romLen;
  Serial.print("Len: ");Serial.println(romLen);
 	file.close();
}
// Funzione per leggere una riga dal file

/////////////////////////////
bool leggiRiga(FatFile &f, char* buf, int max) {
    int i = 0;
    while (i < max-1 && f.available()) {
        char c = f.read();
        if (c == '\n') break;
        if (c == '\r') {
            if (f.available() && f.peek() == '\n') f.read();
            break;
        }
        buf[i++] = c;
    }
    buf[i] = '\0';
    return i > 0 || f.available();
}
/////////////////////////////////////////////////////////////////////////////////////////
//////////////////////////////////* load .cfg file */////////////////////////////////////
/////////////////////////////////////////////////////////////////////////////////////////
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
void loop()
{
    uint32_t pins;
    uint32_t addr;
    uint32_t dataOut=0;
    uint16_t dataWrite=0;
 
  Serial.println("Loop");

	// overclocking isn't necessary for most functions - but XEGS carts weren't working without it
	// I guess we might as well have it on all the time.
  vreg_set_voltage(VREG_VOLTAGE_1_10);
  set_sys_clock_khz(270000, true);
 
  //multicore_launch_core1(core1_main);

  // Initialize the bus state variables

  busLookup[BUS_NACT]  = 4; // 100
  busLookup[BUS_BAR]   = 1; // 001
  busLookup[BUS_IAB]   = 4; // 100
  busLookup[BUS_DWS]   = 2; // 010   // test without dws handling
  busLookup[BUS_ADAR]  = 1; // 001
  busLookup[BUS_DW]    = 4; // 100
  busLookup[BUS_DTB]   = 0; // 000
  busLookup[BUS_INTAK] = 4; // 100


  gpio_init_mask(ALWAYS_OUT_MASK);
  gpio_init_mask(DATA_PIN_MASK);
  gpio_init_mask(BUS_STATE_MASK);
  gpio_set_dir_in_masked(ALWAYS_IN_MASK);
  gpio_set_dir_out_masked(ALWAYS_OUT_MASK);
  gpio_init(LED_PIN);
  gpio_put(LED_PIN,true); 
  gpio_init(RST_PIN);
  
  gpio_set_dir(MSYNC_PIN,GPIO_IN);
  gpio_pull_down(MSYNC_PIN);
  
  sleep_ms(800);
#ifdef intidebug
  RAM[0x163]=2; //1 for debug, 2 for debug with looping
#endif

  resetHigh(); 
  sleep_ms(30);
  resetLow();
  //while (gpio_get(MSYNC_PIN)==1); // wait for Inty powerup
  printf("Inty Pow-ON");
  
  gpio_put(LED_PIN,true);
  memset(ROM,0,BINLENGTH);
  
  for (int i=0;i<(sizeof(_acpirtoII)/2);i++) {
   ROM[i]=_acpirtoII[(i*2)+1] | (_acpirtoII[i*2] << 8);
  }
  memset(RAM,0,sizeof(RAM));
  
 for (int i=0; i<maxHacks; i++) {
  HACK[i]=0;
  HACK_CODE[i]=0;
 }

  slot=1; // 2 slots per splash

  //  [mapping]
  //$0000 - $0dFF = $5000
  mapfrom[0]=0x0;
  mapto[0]=0xdff;
  maprom[0]=0x5000;
  tipo[0]=0;
  page[0]=0;
  addrto[0]=0x5dff;
  mapdelta[0]=maprom[0] - mapfrom[0];
  mapsize[0]=mapto[0] - mapfrom[0];
    
 //[memattr]
 //$8000 - $9FFF = RAM 16
  RAMused=1;
  ramfrom=0x8000;
  mapfrom[1]=0x8000;
  mapto[1]=0x9fff;
  maprom[1]=0x8000;
  tipo[1]=2;
  page[1]=0;
  addrto[1]=0x9fff;
  mapdelta[1]=maprom[1] - mapfrom[1];
  mapsize[1]=mapto[1] - mapfrom[1];
  
  //sleep_ms(200);
  //resetCart();
  sleep_ms(200);
  resetCart();
  sleep_ms(1200);
  // Initial conditions 
  memset(curPath,0,sizeof(curPath));
  curPath[0]='/';
  Serial.print("Curpath:");
  Serial.println(curPath);
  sleep_ms(800);
	
  RAM[0x889]=0;
  sleep_ms(800);
	RAM[0x119]=1;
   	 
  RAM[0x119]=123;
   gpio_put(LED_PIN,true);
  
  
  IntyMenu(1);
  
  while (1) {
     cmd_executing=false;
     cmd=RAM[0x889];
     RAM[0x119]=0;
 
     if ((cmd>0)&&!(cmd_executing)) {
      switch (cmd) {
      case 1:  // read file list
        cmd_executing=true;
        RAM[0x889]=0;
    	  IntyMenu(1);
	 	    RAM[0x119]=1;
      	sleep_ms(900);
        Serial.print("new path:");Serial.println(curPath);
      	break;
      case 2:  // run file list
        cmd_executing=true;
    	  RAM[0x889]=0;
	 	    LoadGame();
		    RAM[0x119]=1;
      	sleep_ms(1400);
      	break;
      case 3:  // next page
	      cmd_executing=true;
        RAM[0x889]=0;
        IntyMenu(2);
		    RAM[0x119]=1;
        Serial.println("next page");
        sleep_ms(900);
      	break;
      case 4:  // prev page
        cmd_executing=true;
        RAM[0x889]=0; 
     	  IntyMenu(3);
		    RAM[0x119]=1;
        Serial.println("prev page");
        sleep_ms(900);
	 	    break;
	    case 5:  // up dir
        cmd_executing=true;
        RAM[0x889]=0; 
     	  DirUp();
		    IntyMenu(1);
		    RAM[0x119]=1;
        sleep_ms(900);
        Serial.print("Dirup->new path:");Serial.println(curPath);
	 	    break;
    }     
   }
  }
}
 	
#pragma GCC pop_options

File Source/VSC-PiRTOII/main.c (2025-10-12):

/*
//                       PiRTO II Flash MultiCART by Andrea Ottaviani 2024
//
//  Intellivision flash multicart based on Raspberry Pico board -
//
//  More info on https://github.com/aotta/ 
//
//   parts of code are directly from the A8PicoCart project by Robin Edwards 2023
//  
//   Needs to be a release NOT debug build for the cartridge emulation to work
// 
//   Edit myboard.h depending on the type of flash memory on the pico clone//
//
//   v. 1.0 2024-05-04 : Initial version for Pi Pico 
//
*/



#include <stdio.h>
#include <string.h>

#include "pico/stdlib.h"
#include "pico/time.h"
#include "tusb.h"

#include "inty_cart.h"
#include "fatfs_disk.h"

//void cdc_task(void);


//--------------------------------------------------------------------+
// USB CDC
//--------------------------------------------------------------------+
void cdc_task(void)
{
  // connected() check for DTR bit
  // Most but not all terminal client set this when making connection
  // if ( tud_cdc_connected() )
  {
    // connected and there are data available
    if ( tud_cdc_available() )
    {
      // read data
      char buf[64];
      uint32_t count = tud_cdc_read(buf, sizeof(buf));
      (void) count;

      // Echo back
      // Note: Skip echo by commenting out write() and write_flush()
      // for throughput test e.g
      //    $ dd if=/dev/zero of=/dev/ttyACM0 count=10000
      tud_cdc_write(buf, count);
      tud_cdc_write_flush();
    }
  }
}

// Invoked when cdc when line state changed e.g connected/disconnected
void tud_cdc_line_state_cb(uint8_t itf, bool dtr, bool rts)
{
  (void) itf;
  (void) rts;

  // TODO set some indicator
  if ( dtr )
  {
    // Terminal connected
  }else
  {
    // Terminal disconnected
  }
}

// Invoked when CDC interface received data from host
void tud_cdc_rx_cb(uint8_t itf)
{
  (void) itf;
}


int main(void)
{
   tusb_init();
   stdio_init_all();   // for serial output, via printf()
   
    tud_init(BOARD_TUD_RHPORT);
    gpio_init(MSYNC_PIN);
    gpio_set_dir(MSYNC_PIN,false);
    gpio_init(RST_PIN);
    gpio_set_dir( RST_PIN,true);
    //gpio_put(RST_PIN,true);
    sleep_ms(2);
   
    while(1) {          
    
   // since v. 1.04 adopted gtortone (Minty) startup routine since it seems more compatible with different Inty'sversions     
   // reset interval in ms
   int t = 100;

   while (gpio_get(MSYNC_PIN) == 0 && to_ms_since_boot(get_absolute_time()) < 2000) {   // wait for Inty powerup
      if (to_ms_since_boot(get_absolute_time()) > t) {
         t += 100;
         gpio_put(RST_PIN, false);
         sleep_ms(5);
         gpio_put(RST_PIN, true);
      }
   }

   // check why loop is ended...
   if (gpio_get(MSYNC_PIN) == 1)
      Inty_cart_main();

/*
    while (to_ms_since_boot(get_absolute_time()) < 150)  // was 200, to test
    {
      if ((gpio_get(MSYNC_PIN)==1))
   //if ((gpio_get(1)==1)) // alternate_boot
   //      gpio_put(RST_PIN,false);
        Inty_cart_main();
    }

     
       // init device stack on configured roothub port
       // we are presumably powered from USB
       // enter USB mass storage mode
     //  tud_init(BOARD_TUD_RHPORT);
     //  stdio_init_all();   // for serial output, via printf()
     //  printf("Start\n");
*/
       while (1) {
          tud_task(); // tinyusb device task
         
          cdc_task();
       }
    
    }
   return 0;
}

//--------------------------------------------------------------------+
// Device callbacks
//--------------------------------------------------------------------+

// Invoked when device is mounted
void tud_mount_cb(void)
{
  printf("Device mounted\n"); 
  if (!mount_fatfs_disk())
    create_fatfs_disk();
}

// Invoked when device is unmounted
void tud_umount_cb(void)
{
  printf("Device unmounted\n");  
}

// Invoked when usb bus is suspended
// remote_wakeup_en : if host allow us  to perform remote wakeup
// Within 7ms, device must draw an average of current less than 2.5 mA from bus
void tud_suspend_cb(bool remote_wakeup_en)
{
  (void) remote_wakeup_en;
//  blink_interval_ms = BLINK_SUSPENDED;
}

// Invoked when usb bus is resumed
void tud_resume_cb(void)
{
//  blink_interval_ms = BLINK_MOUNTED;
}

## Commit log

2024-08-07 Update inty_cart.c
    bug fixed in hacks check
    [inty_cart.c]
2024-10-28 New improved shell version by Eskimo
    [PiRTO_II-Cart-Bottom+Logo.stl, PiRTO_II-Cart-Top.stl]
2025-04-28 bug in hacks sectino fixed
    [inty_cart.c]
2025-10-03 V.1.04 bug fix Missile Domination
    [inty_cart.c]
2025-10-12 Used initialization fix used by gtortone
    Used initialization fix used by gtortone in his "Minty" for better compatibility
    [main.c]
2025-10-16 Add files via upload
    Porting to Arduino IDE (since V.1.05) - need flash reformat!!!
2025-10-16 Add files via upload
    further bugfixes
    [PiRTOII.ino]
